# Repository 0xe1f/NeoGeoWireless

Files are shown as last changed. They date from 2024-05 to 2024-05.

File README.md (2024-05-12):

NeoGeoWireless
====

NeoGeoWireless is a wireless Neo Geo controller, built on top of a cheap
aftermarket 2.4 GHz SNES Controller.  
It works by converting the SNES controller signals (that would normally go to
the SNES) to format compatible with Neo-Geo, in the process adding features,
like Turbo and Macro button support.

## Requirements

[2.4GHz SNES Controller](https://www.amazon.com/gp/product/B09H4826RV/)  
3x 0.1uF Capacitors  
LED (to display turbo status)  
Atmega328P  
Neo-Geo controller DIN connector, hopefully cannibalized from NG Controller
extension cords  
Custom PCB schematics for the receiver add-on board
([KiCad](schematics/rx-snes/), [PDF](docs/schematic.pdf))  
[3D-printed case](stl/NGRcvrSNES.stl) ([slightly roomier version](stl/NGRcvrSNESDev.stl) for prototyping)  
[Firmware](build/) for the Atmega328P (`make writefuses && make install`)  

## Examples

### Plug front

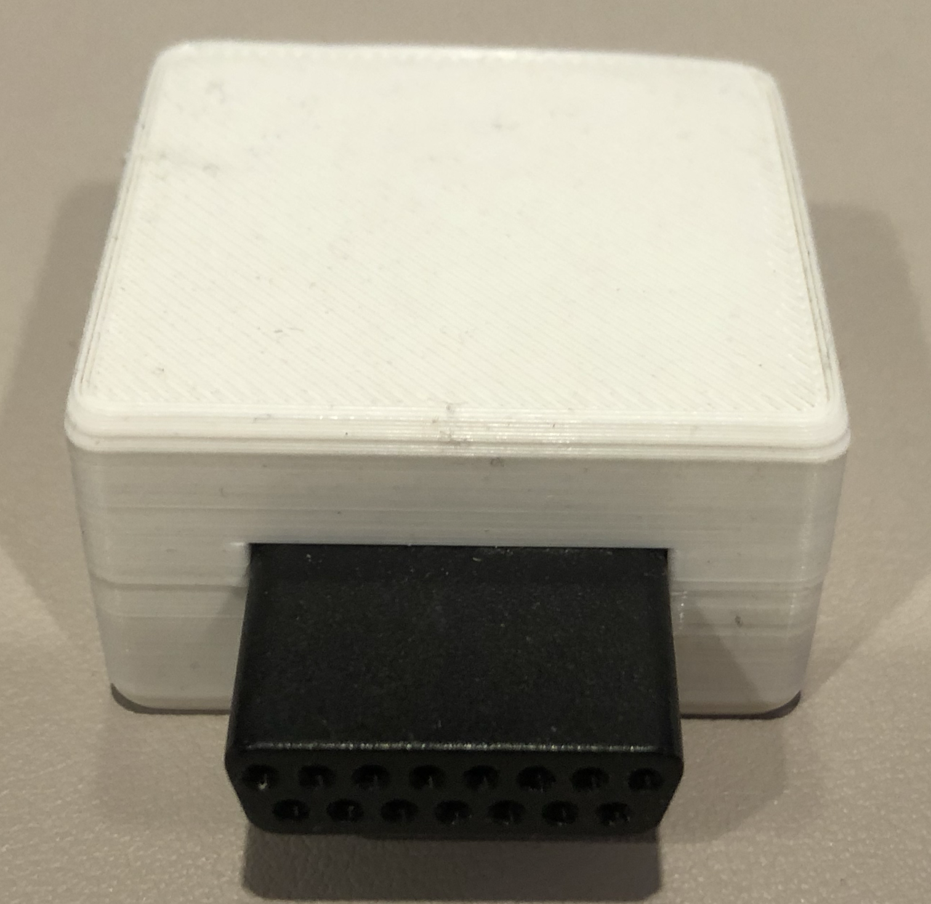
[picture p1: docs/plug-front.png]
plug
  

### SNES receiver board

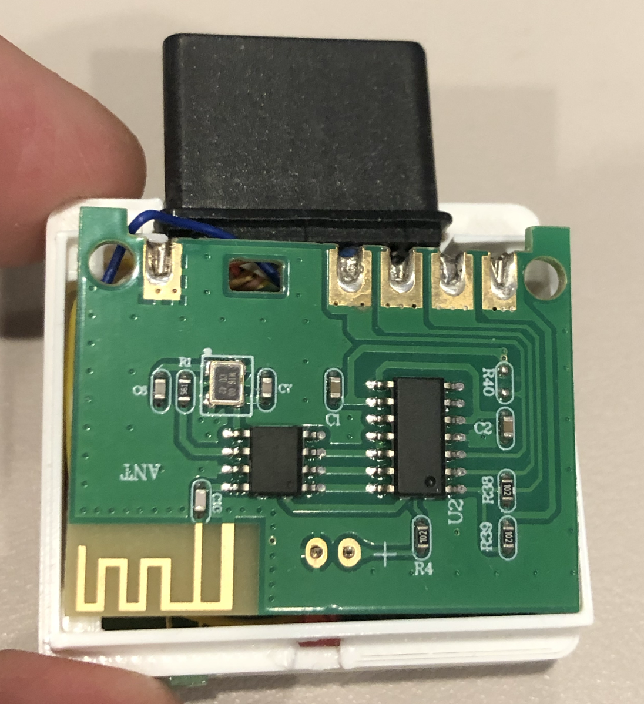
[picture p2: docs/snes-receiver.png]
  

### Add-on board

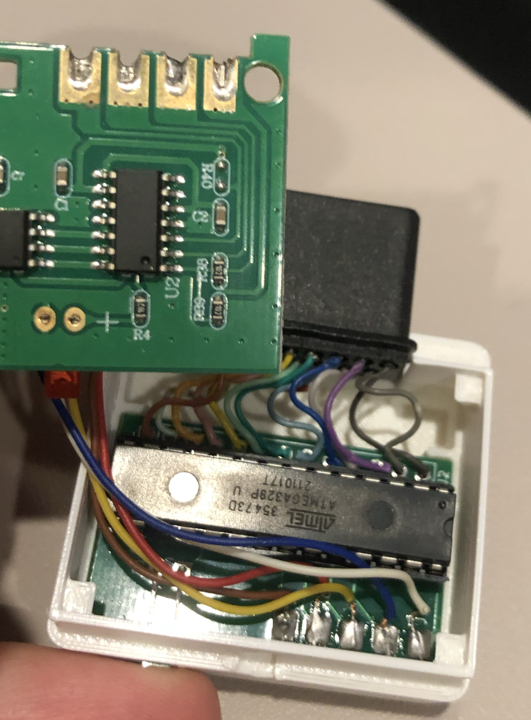
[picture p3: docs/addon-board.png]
  

### Neo Geo Controller port pinout

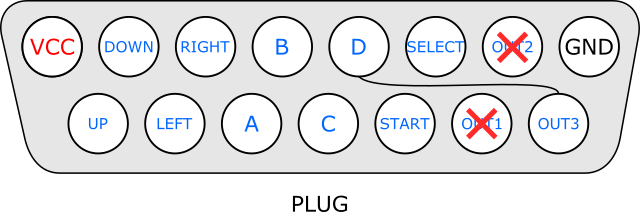
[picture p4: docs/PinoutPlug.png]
pinout
  

### Button mapping
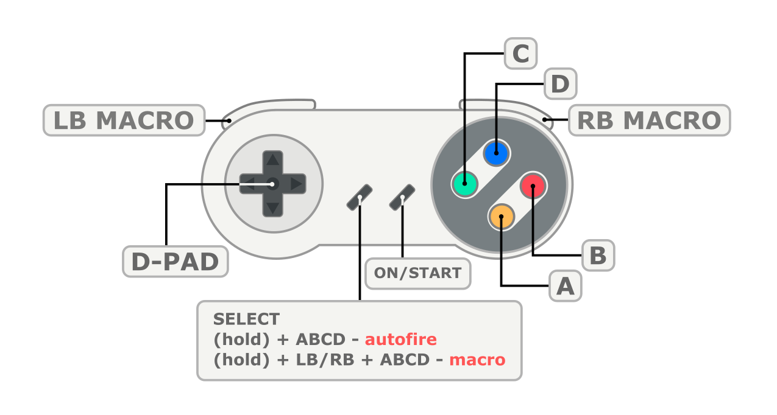
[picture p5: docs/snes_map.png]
controls


## LICENSE

```
Copyright 2021-2024, Akop Karapetyan

Licensed under the Apache License, Version 2.0 (the "License");
you may not use this file except in compliance with the License.
You may obtain a copy of the License at

    http://www.apache.org/licenses/LICENSE-2.0

Unless required by applicable law or agreed to in writing, software
distributed under the License is distributed on an "AS IS" BASIS,
WITHOUT WARRANTIES OR CONDITIONS OF ANY KIND, either express or implied.
See the License for the specific language governing permissions and
limitations under the License.
```

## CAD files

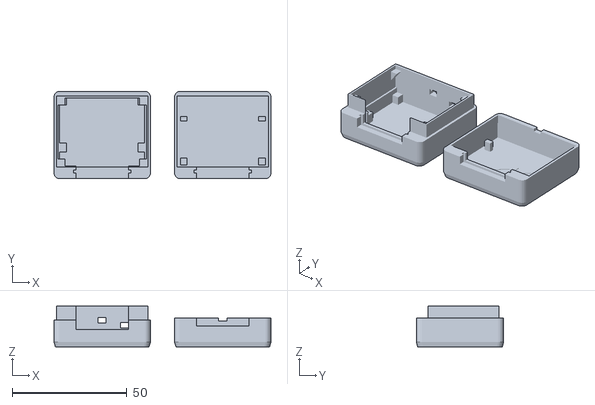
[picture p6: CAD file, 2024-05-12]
stl/NGRcvrSNESDev.stl
94.5 x 38.0 x 17.7

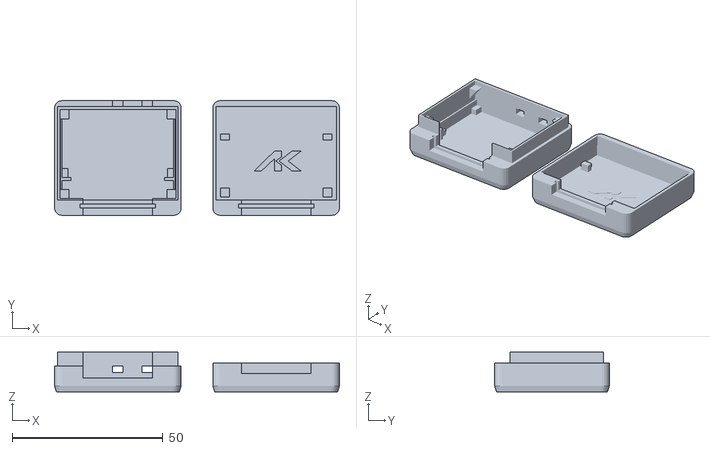
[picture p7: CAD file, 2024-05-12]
stl/NGRcvrSNES.stl
94.5 x 38.0 x 13.2

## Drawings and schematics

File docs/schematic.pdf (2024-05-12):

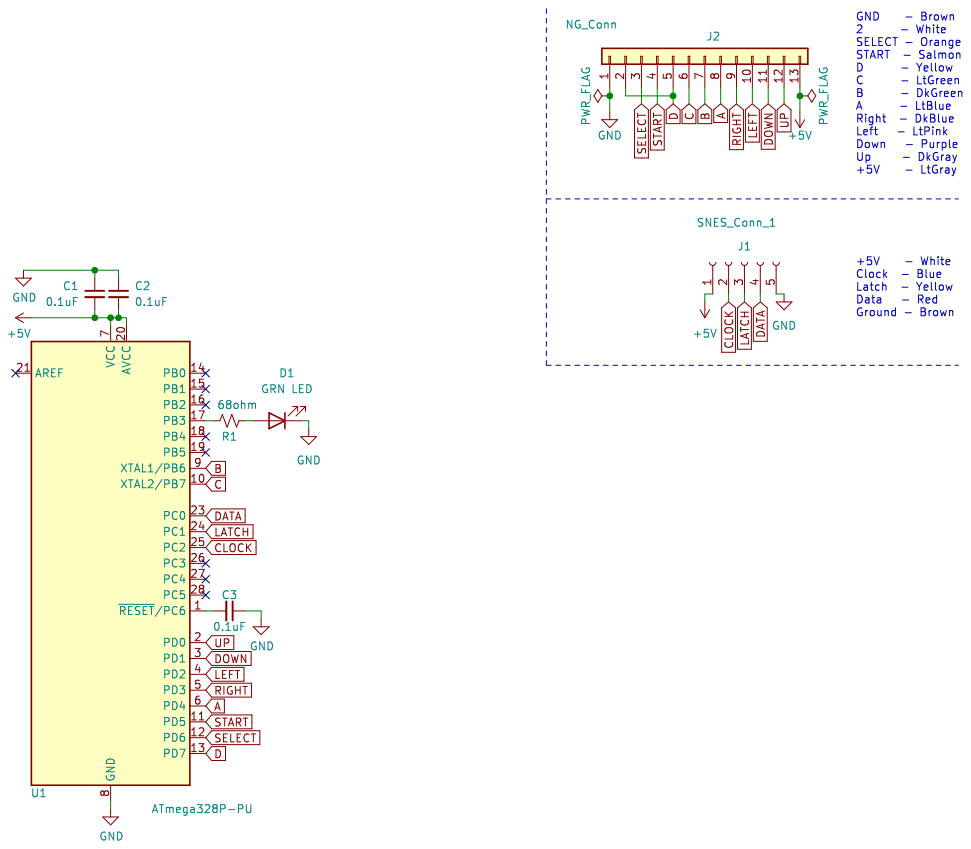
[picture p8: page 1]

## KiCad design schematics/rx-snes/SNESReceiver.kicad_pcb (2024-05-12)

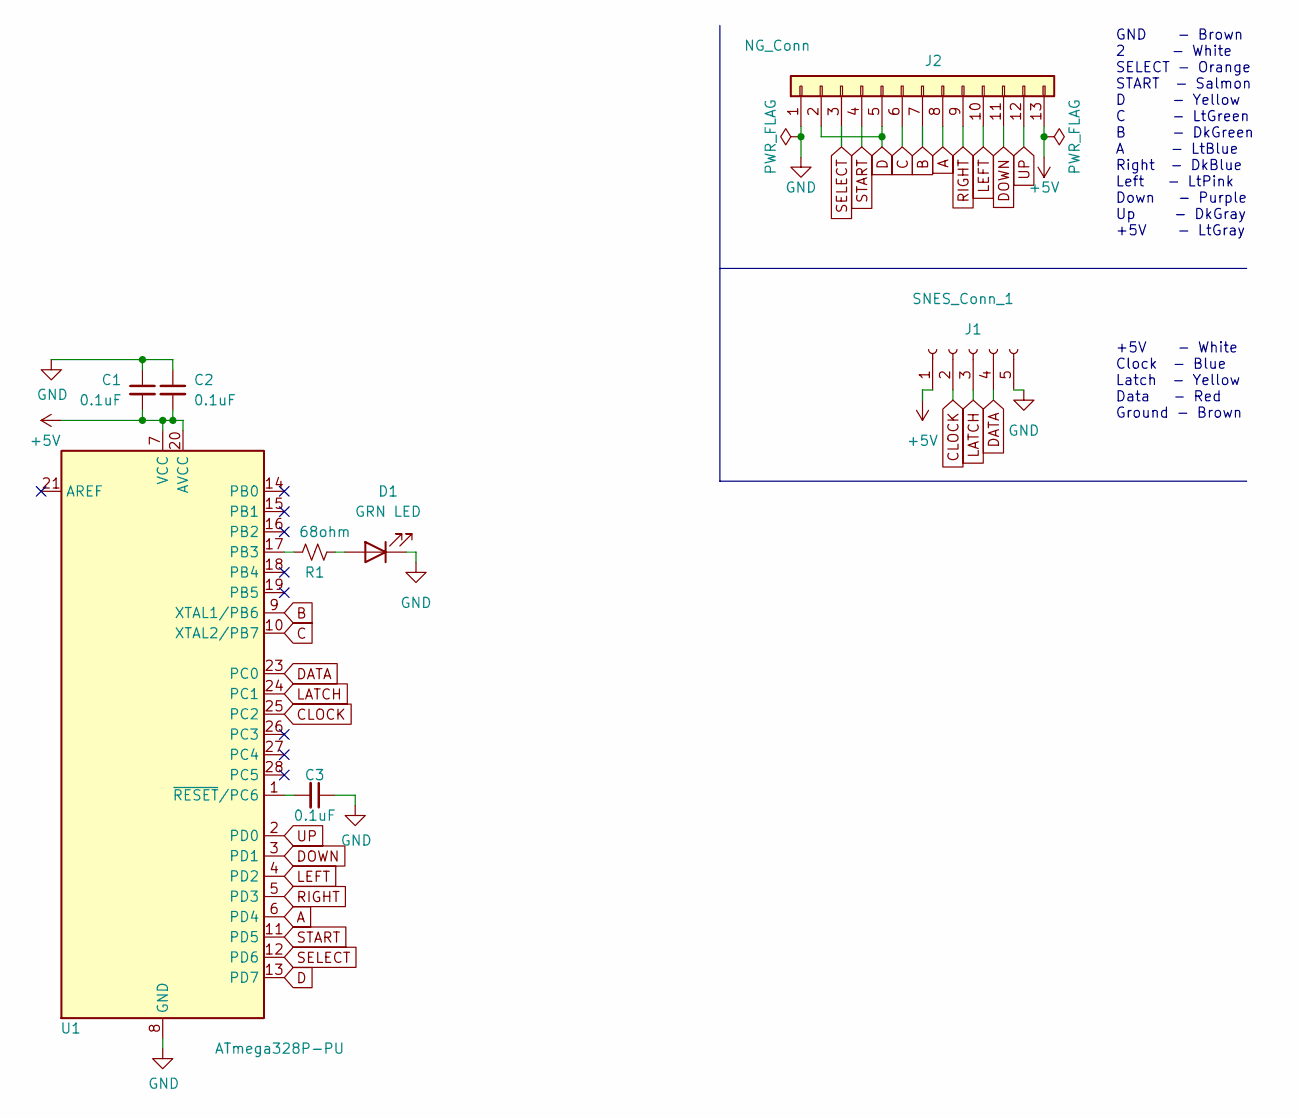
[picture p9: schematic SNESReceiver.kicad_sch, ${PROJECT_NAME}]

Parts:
C1, C2, C3: 0.1uF; C_0805_2012Metric_Pad1.18x1.45mm_HandSolder
D1: GRN LED; LED_Rectangular_W3.0mm_H2.0mm
J1: SNES_Conn_1; Wide5PinConnector
J2: NG_Conn; PinHeader_1x13_P2.54mm_Vertical
R1: 68ohm; R_0805_2012Metric_Pad1.20x1.40mm_HandSolder
U1: ATmega328P-PU; DIP-28_W7.62mm

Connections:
+5V: C1.2, C2.2, J1.1, J2.13, U1.7 (VCC), U1.20 (AVCC)
A: J2.8, U1.6 (PD4)
B: J2.7, U1.9 (XTAL1/PB6)
C: J2.6, U1.10 (XTAL2/PB7)
CLOCK: J1.2, U1.25 (PC2)
D: J2.2, J2.5, U1.13 (PD7)
DATA: J1.4, U1.23 (PC0)
DOWN: J2.11, U1.3 (PD1)
GND: C1.1, C2.1, C3.1, D1.1 (K), J1.5, J2.1, U1.8 (GND), U1.22 (GND)
LATCH: J1.3, U1.24 (PC1)
LEFT: J2.10, U1.4 (PD2)
unnamed: C3.2, U1.1 (~RESET/PC6)
unnamed: D1.2 (A), R1.2
unnamed: R1.1, U1.17 (PB3)
RIGHT: J2.9, U1.5 (PD3)
SELECT: J2.3, U1.12 (PD6)
START: J2.4, U1.11 (PD5)
UP: J2.12, U1.2 (PD0)

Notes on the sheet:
+5V - White Clock - Blue Latch - Yellow Data - Red Ground - Brown
GND - Brown 2 - White SELECT - Orange START - Salmon D - Yellow C - LtGreen B - DkGreen A - LtBlue Right - DkBlue Left - LtPink Down - Purple Up - DkGray +5V - LtGray

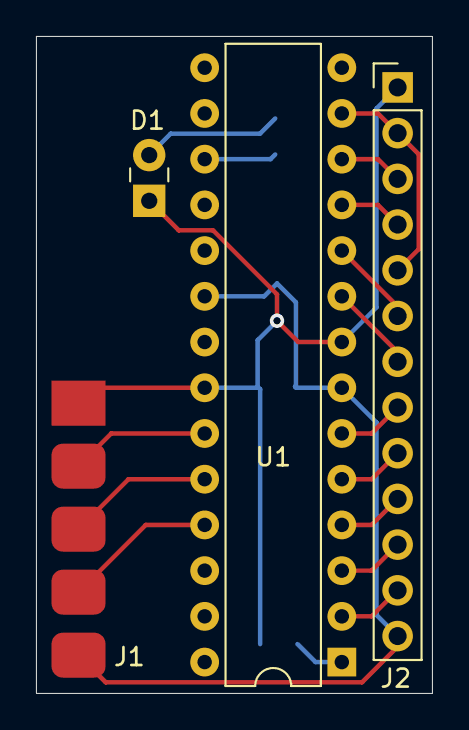
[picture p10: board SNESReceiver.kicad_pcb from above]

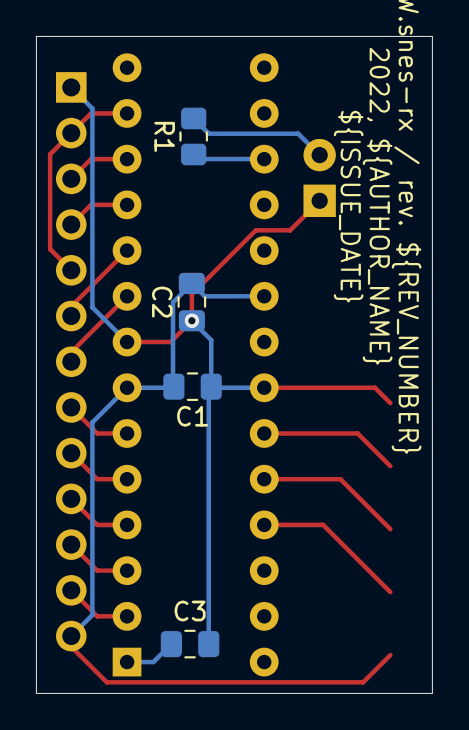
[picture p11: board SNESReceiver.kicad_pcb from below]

Board: 2 copper layers, 22.0 x 36.5 mm, 8 parts (4 on the bottom side), 18 nets.
